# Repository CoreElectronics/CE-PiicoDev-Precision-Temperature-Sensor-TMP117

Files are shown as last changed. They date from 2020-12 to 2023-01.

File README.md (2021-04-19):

# PiicoDev® Precision Temperature Sensor TMP117

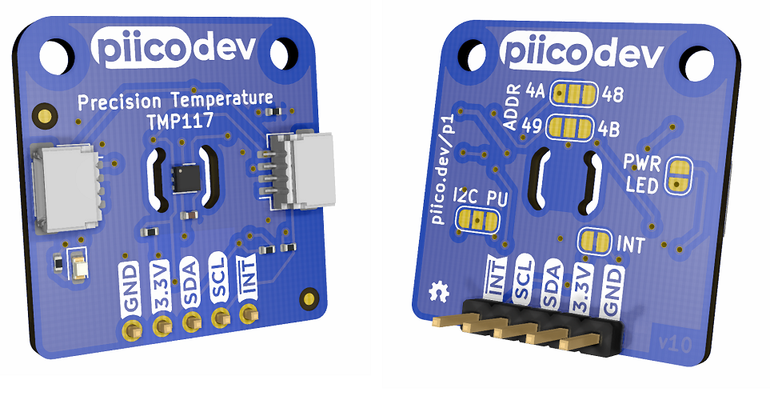
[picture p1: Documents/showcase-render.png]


This is the repo for the Core Electronics [PiicoDev Precision Temperature Sensor TMP117](https://core-electronics.com.au/catalog/product/view/sku/CE07502).

The PiicoDev Precision Temperature Sensor features a low-power, high precision TMP117 with 16-bit resolution and an accuracy of ±0.1°C (across -20°C to +50°C) with no calibration required. The full operating range is -55°C to +150°C.

- Small size, high accuracy
- PiicoDev connector, compatible with Qwiic and STEMMA QT (3.3V only)
- 2.54mm breakout for breadboarding/prototyping
- Manufactured and [supported](https://core-electronics.com.au/contacts/) in Australia by Core Electronics

**Technical Specifications:**

- 4 configurable I2C addresses. Default: 0x48
- Dimensions: 25.4x25.4mm
- Mounting Holes: 2x M2.5
- TMP117:
  - ±0.1°C from -20°C to +50°C
  - ±0.15°C from -40°C to +70°C
  - ±0.2°C from -40°C to +100°C
  - ±0.25°C from -55°C to +125°C
  - ±0.3°C from -55°C to +150°C
  - 0.0078°C resolution (1 LSB)

# License
This project is open source - please review the LICENSE.md file for further licensing information.

If you have any technical questions, or concerns about licensing, please contact technical support on the [Core Electronics forums](https://forum.core-electronics.com.au/).

# Attribution
The hardware design of this module is influenced by the design from [Sparkfun](https://github.com/sparkfun/SparkFun_High_Precision_Temperature_Sensor_TMP117_Qwiic).

*\"PiicoDev\" and the PiicoDev logo are trademarks of Core Electronics Pty Ltd.*

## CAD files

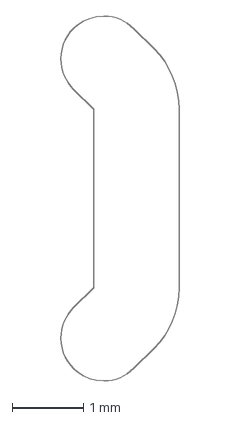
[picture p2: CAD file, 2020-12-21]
PCB/construction-lines/slot.dxf
1.66 x 5.12 mm

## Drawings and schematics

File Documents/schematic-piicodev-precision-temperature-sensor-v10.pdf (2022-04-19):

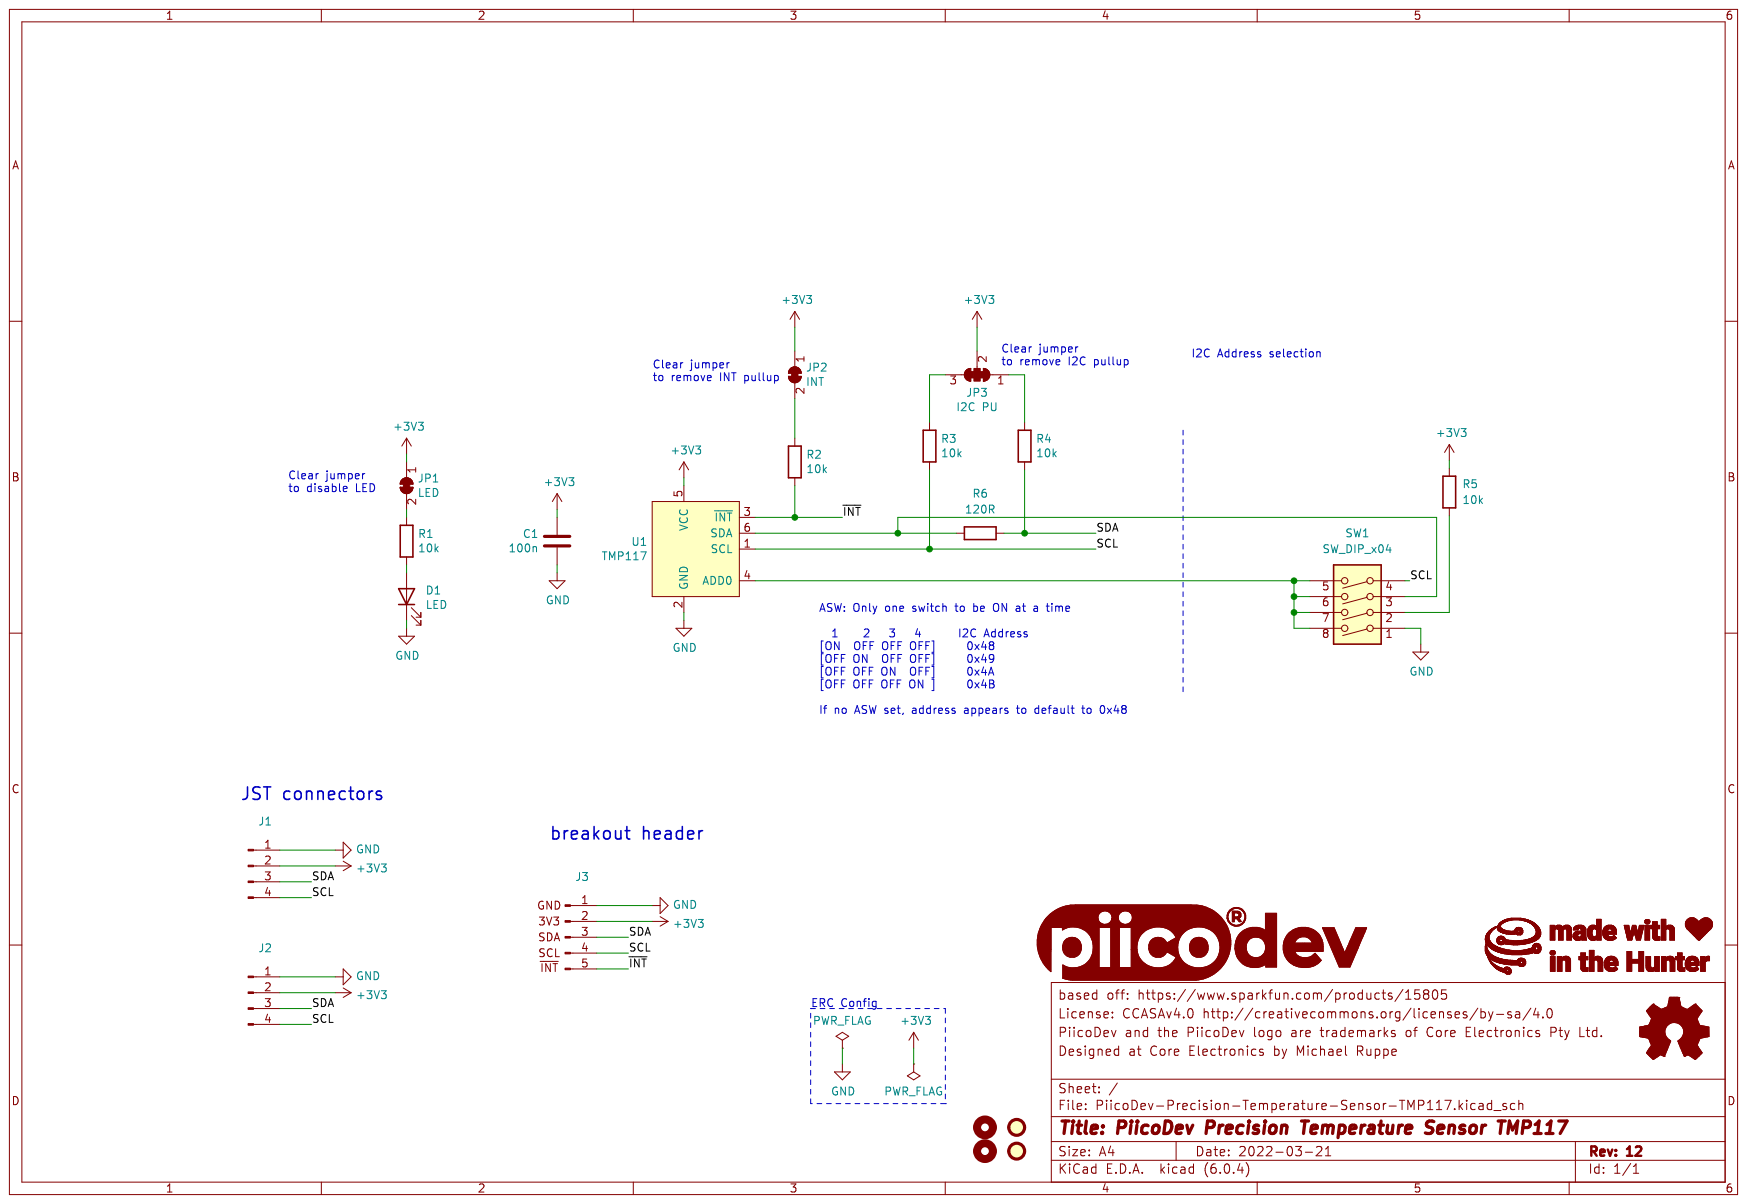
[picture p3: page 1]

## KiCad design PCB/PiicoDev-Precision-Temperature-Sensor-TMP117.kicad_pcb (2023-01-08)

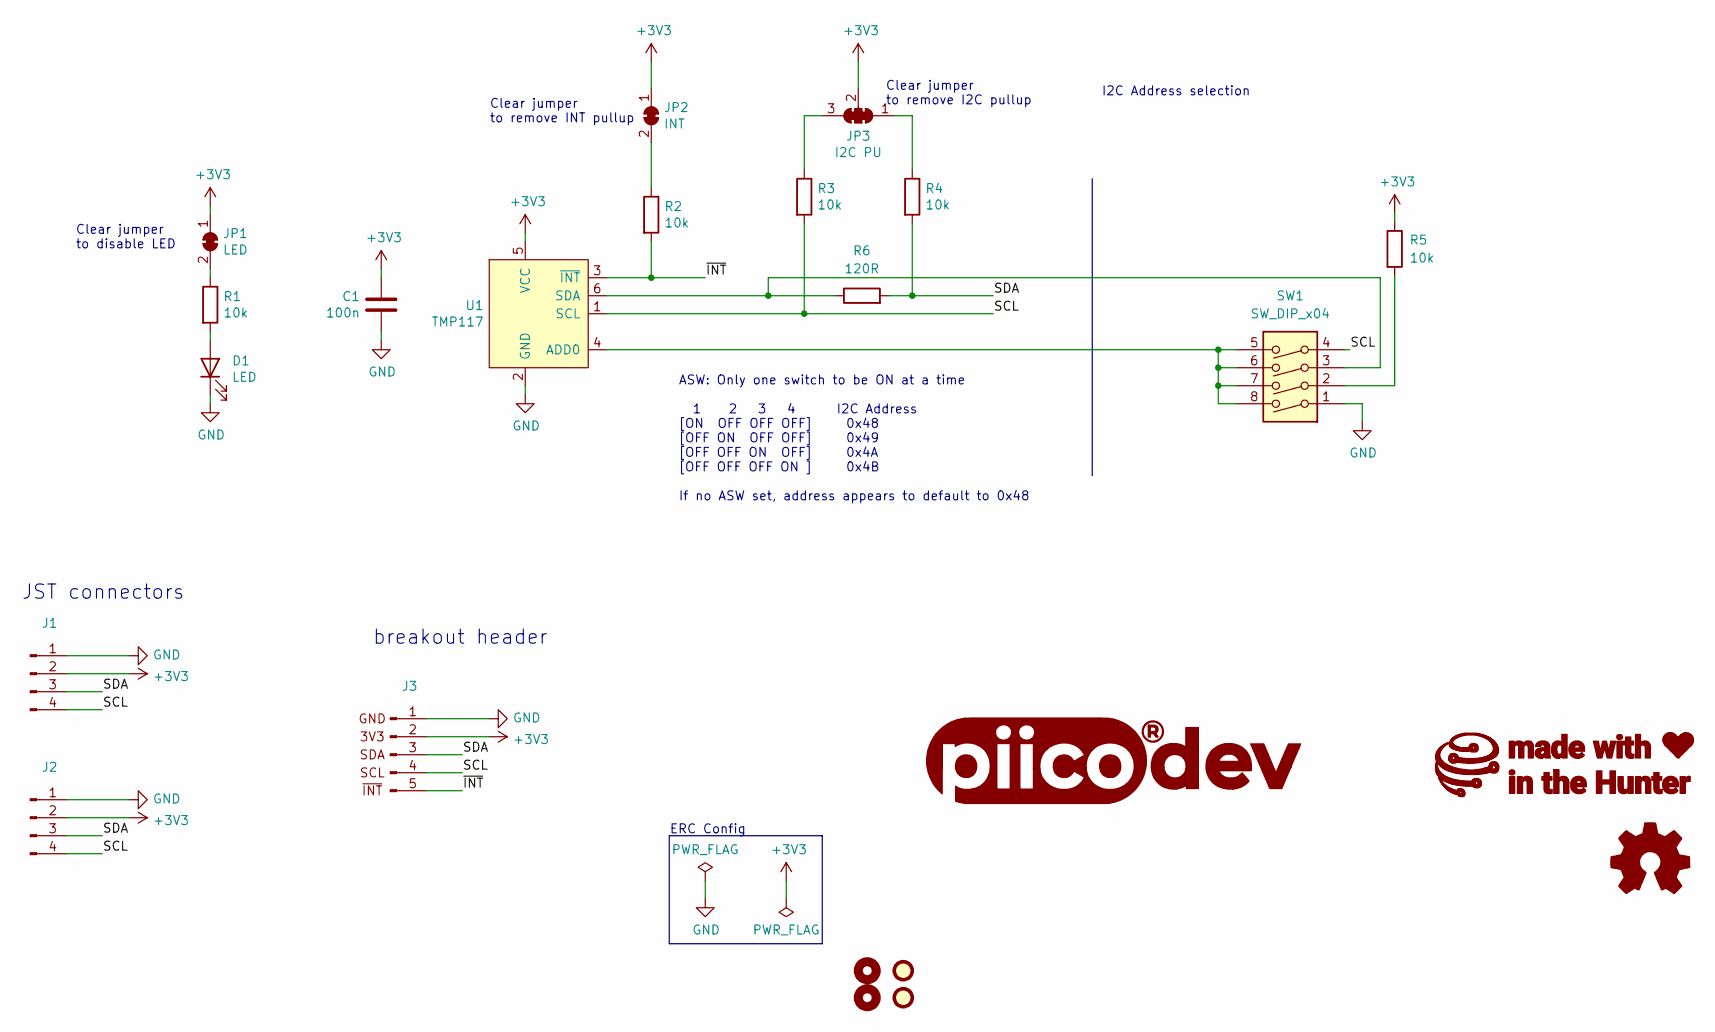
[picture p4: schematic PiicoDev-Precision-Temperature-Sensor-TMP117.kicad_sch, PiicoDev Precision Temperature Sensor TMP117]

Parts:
C1: 100n; C_0402_1005Metric
D1: LED; LED_0603_1608Metric
FID1, FID2: Fiducial; Fiducial_1mm_Mask2mm
G1: LOGO_CoreElectronics_no-text; CoreElectronics_logo_5mm
G2: LOGO_piico; piicodev_logo_14.2x3.4mm
G3: LOGO_made-with-love; piicodev_logo_14.2x3.4mm
H1, H4: MountingHole; MountingHole_2.7mm_M2.5
J1, J2: JST_SH_SM04B-SRSS-TB_1x04-1MP_P1.00mm_Horizontal
J3: PiicoDev_header_5pin_INT
JP1: LED; SolderJumper-2_P1.3mm_Bridged_RoundedPad1.0x1.5mm
JP2: INT; SolderJumper-2_P1.3mm_Bridged_RoundedPad1.0x1.5mm
JP3: I2C PU; SolderJumper-3_P1.3mm_Closed_RoundedPad1.0x1.5mm_NumberLabe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
LOGO1: Logo_Open_Hardware_Small; oshw
R1, R2, R3, R4, R5: 10k; R_0402_1005Metric
R6: 120R; R_0402_1005Metric
SW1: SW_DIP_x04; SW_DIP_x04_Slide_CHS-04A1
U1: TMP117; WSON-6-1EP_2x2mm_P0.65mm_EP1x1.6mm

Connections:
+3V3: C1.2, J1.2, J2.2, J3.2, JP1.1 (A), JP2.1 (A), JP3.2 (C), R5.1, U1.5 (VCC)
/SCL: J1.4, J2.4, J3.4, R3.2, SW1.4, U1.1 (SCL)
/SDA: J1.3, J2.3, J3.3, R4.2, R6.2
/~INT: J3.5, R2.2, U1.3 (~INT)
GND: C1.1, D1.1 (K), J1.1, J2.1, J3.1, SW1.1, U1.2 (GND)
unnamed: D1.2 (A), R1.2
unnamed: JP1.2 (B), R1.1
unnamed: JP2.2 (B), R2.1
unnamed: JP3.1 (A), R4.1
unnamed: JP3.3 (B), R3.1
unnamed: R5.2, SW1.2
unnamed: R6.1, SW1.3, U1.6 (SDA)
unnamed: SW1.5, SW1.6, SW1.7, SW1.8, U1.4 (ADD0)

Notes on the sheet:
JST connectors
Clear jumper to remove I2C pullup
ASW: Only one switch to be ON at a time 1 2 3 4 I2C Address [ON OFF OFF OFF] 0x48 [OFF ON OFF OFF] 0x49 [OFF OFF ON OFF] 0x4A [OFF OFF OFF ON ] 0x4B If no ASW set, address appears to default to 0x48
breakout header
ERC Config
I2C Address selection
Clear jumper to remove INT pullup
Clear jumper to disable LED

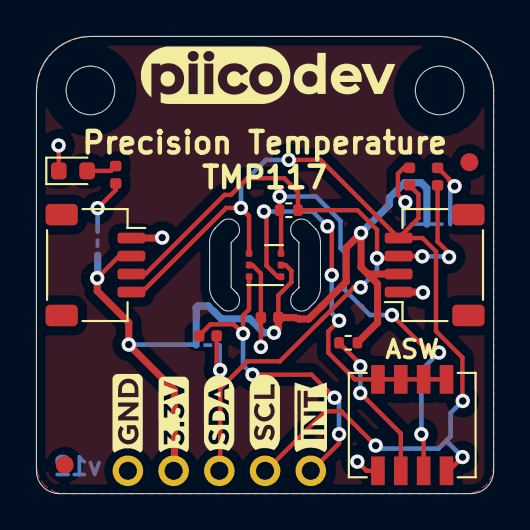
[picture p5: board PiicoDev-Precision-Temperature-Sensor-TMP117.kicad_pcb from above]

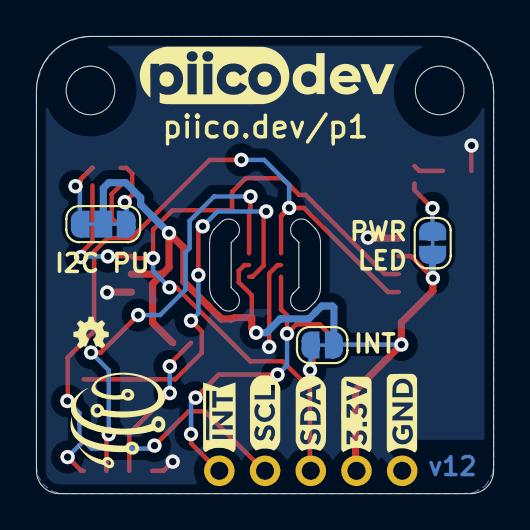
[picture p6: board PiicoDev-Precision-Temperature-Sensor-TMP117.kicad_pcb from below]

Board: 2 copper layers, 25.4 x 25.4 mm, 24 parts (7 on the bottom side), 13 nets.

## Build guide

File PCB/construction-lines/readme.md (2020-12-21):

# Construction Lines

The routed-slot surrounding the temperature sensor was constructed in a vector-editor and imported into KiCad as a .dxf

It was far easier to capture the geometry this way. The origin-files are preserved here.

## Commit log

2021-03-22 Update title blocks
    [PiicoDev-Precision-Temperature-Sensor-TMP117.kicad_pcb, PiicoDev-Precision-Temperature-Sensor-TMP117.sch]
2021-03-22 Add schematic pdf
2021-07-28 Update R1 to 4k7
    New LED is more efficient, use larger resistor. Optimise 1k out of the BOM
    [PiicoDev-Precision-Temperature-Sensor-TMP117.kicad_pcb, PiicoDev-Precision-Temperature-Sensor-TMP117.sch]
2021-12-30 v11 Update
    Change resistor values
    Add DIP switch and remove ADR jumper
    Update graphic labels
    Remove solder mask between jumper pads
    Update text formatting
    [PiicoDev-Precision-Temperature-Sensor-TMP117.kicad_pcb, PiicoDev-Precision-Temperature-Sensor-TMP117.sch]
2022-03-21 v12 Update
    Migrate to KiCad 6.0
    Add 120R resistor
    Add 4-bit DIP SW
    [PiicoDev-Precision-Temperature-Sensor-TMP117.kicad_pcb, PiicoDev-Precision-Temperature-Sensor-TMP117.kicad_sch, PiicoDev-Precision-Temperature-Sensor-TMP117.sch]
2022-03-24 Tweak thermal holes
    [PiicoDev-Precision-Temperature-Sensor-TMP117.kicad_pcb]
2022-04-19 add v12 comments, update schematic pdf
    [PiicoDev-Precision-Temperature-Sensor-TMP117.kicad_sch, PiicoDev-Precision-Temperature-Sensor-TMP117.sch]

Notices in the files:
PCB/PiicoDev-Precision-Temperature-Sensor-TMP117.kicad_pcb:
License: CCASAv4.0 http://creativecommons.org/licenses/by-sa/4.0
